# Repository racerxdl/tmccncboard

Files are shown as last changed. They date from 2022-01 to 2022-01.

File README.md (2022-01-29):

# tmccncboard

TMC2209 GRBL-ESP32 CNC Board

Made with Kicad 6.0

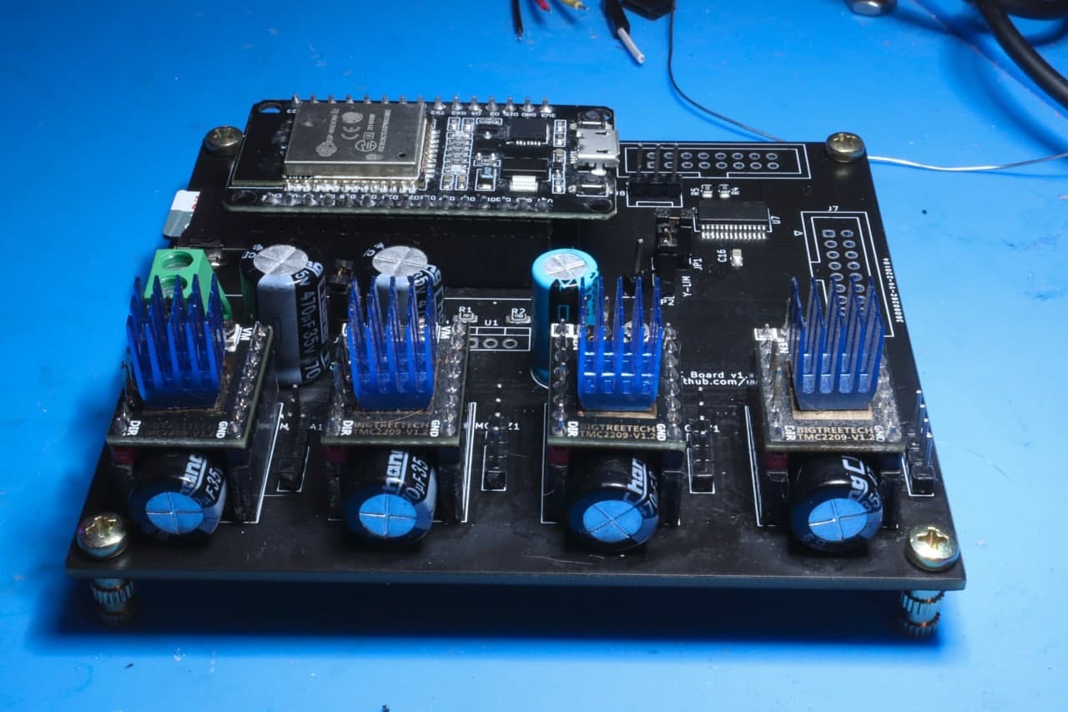
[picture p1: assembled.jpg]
Assembled Board


# FluidNC Configuration

This is the current profile I'm using for [FluidNC](https://github.com/bdring/FluidNC). Its currently WIP and should be used with care.

```yaml
board: Teske's Lab TMC CNC
name: TMCCNC
stepping:
  engine: RMT
  idle_ms: 255
  pulse_us: 2
  dir_delay_us: 1
  disable_delay_us: 0

axes:
  shared_stepper_disable_pin: gpio.27
  x:
    steps_per_mm: 1600.000
    max_rate_mm_per_min: 5000.000
    acceleration_mm_per_sec2: 100.000
    max_travel_mm: 250.000
    soft_limits: false
    homing:
      cycle: 2
      positive_direction: false
      mpos_mm: 150.000
      feed_mm_per_min: 100.000
      seek_mm_per_min: 200.000
      settle_ms: 500
      seek_scaler: 1.100
      feed_scaler: 1.100

    motor0:
      limit_neg_pin: NO_PIN
      limit_pos_pin: NO_PIN
      limit_all_pin: gpio.36
      hard_limits: false
      pulloff_mm:1.000

      tmc_2209:
        uart:
          txd_pin: gpio.17
          rxd_pin: gpio.16
        run_mode: StealthChop
        homing_mode: StallGuard
        step_pin: gpio.2
        direction_pin: gpio.4
        addr: 0
        r_sense_ohms: 0.110
        run_amps: 1.000
        hold_amps: 0.500
        microsteps: 16
  y:
    steps_per_mm: 400.000
    max_rate_mm_per_min: 5000.000
    acceleration_mm_per_sec2: 100.000
    max_travel_mm: 490.000
    soft_limits: false
    homing:
      cycle: 2
      positive_direction: true
      mpos_mm: 150.000
      feed_mm_per_min: 100.000
      seek_mm_per_min: 200.000
      settle_ms: 500
      seek_scaler: 1.100
      feed_scaler: 1.100

    motor0:
      limit_neg_pin: NO_PIN
      limit_pos_pin: NO_PIN
      limit_all_pin: gpio.39
      hard_limits: false
      pulloff_mm:1.000

      tmc_2209:
        run_mode: StealthChop
        homing_mode: StallGuard
        step_pin: gpio.12
        direction_pin: gpio.14
        addr: 1
        r_sense_ohms: 0.110
        run_amps: 1.000
        hold_amps: 0.500
        microsteps: 16

    motor1:
      limit_neg_pin: NO_PIN
      limit_pos_pin: NO_PIN
      limit_all_pin: gpio.34
      hard_limits: false
      pulloff_mm: 1.000
      tmc_2209:
        run_mode: StealthChop
        homing_mode: StallGuard
        step_pin: gpio.33
        direction_pin: gpio.32
        addr: 3
        r_sense_ohms: 0.110
        run_amps: 1.000
        hold_amps: 0.500
        microsteps: 16

  z:
    steps_per_mm: 400.000
    max_rate_mm_per_min: 5000.000
    acceleration_mm_per_sec2: 100.000
    max_travel_mm: 100.000
    soft_limits: false
    homing:
      cycle: 1
      positive_direction: true
      mpos_mm: 150.000
      feed_mm_per_min: 100.000
      seek_mm_per_min: 800.000
      settle_ms: 500
      seek_scaler: 1.100
      feed_scaler: 1.100

    motor0:
      limit_neg_pin: NO_PIN
      limit_pos_pin: NO_PIN
      limit_all_pin: gpio.35
      hard_limits: false
      pulloff_mm:1.000

      tmc_2209:
        run_mode: StealthChop
        homing_mode: StallGuard
        step_pin: gpio.26
        direction_pin: gpio.25
        addr: 2
        r_sense_ohms: 0.110
        run_amps: 1.000
        hold_amps: 0.500
        microsteps: 16

spi:
  miso_pin: gpio.19
  mosi_pin: gpio.23
  sck_pin: gpio.18

sdcard:
  cs_pin: gpio.5
  card_detect_pin: NO_PIN

probe:
  pin: NO_PIN
  check_mode_start: true

start:
  must_home: false

PWM:
  pwm_hz: 5000
  output_pin: gpio.13
  enable_pin: NO_PIN
  direction_pin: NO_PIN
  disable_with_s0: false
  s0_with_disable: true
  spinup_ms: 1000
  spindown_ms: 1000
  tool_num: 0
  speed_map: 0=0.000% 1000=100.000%

```

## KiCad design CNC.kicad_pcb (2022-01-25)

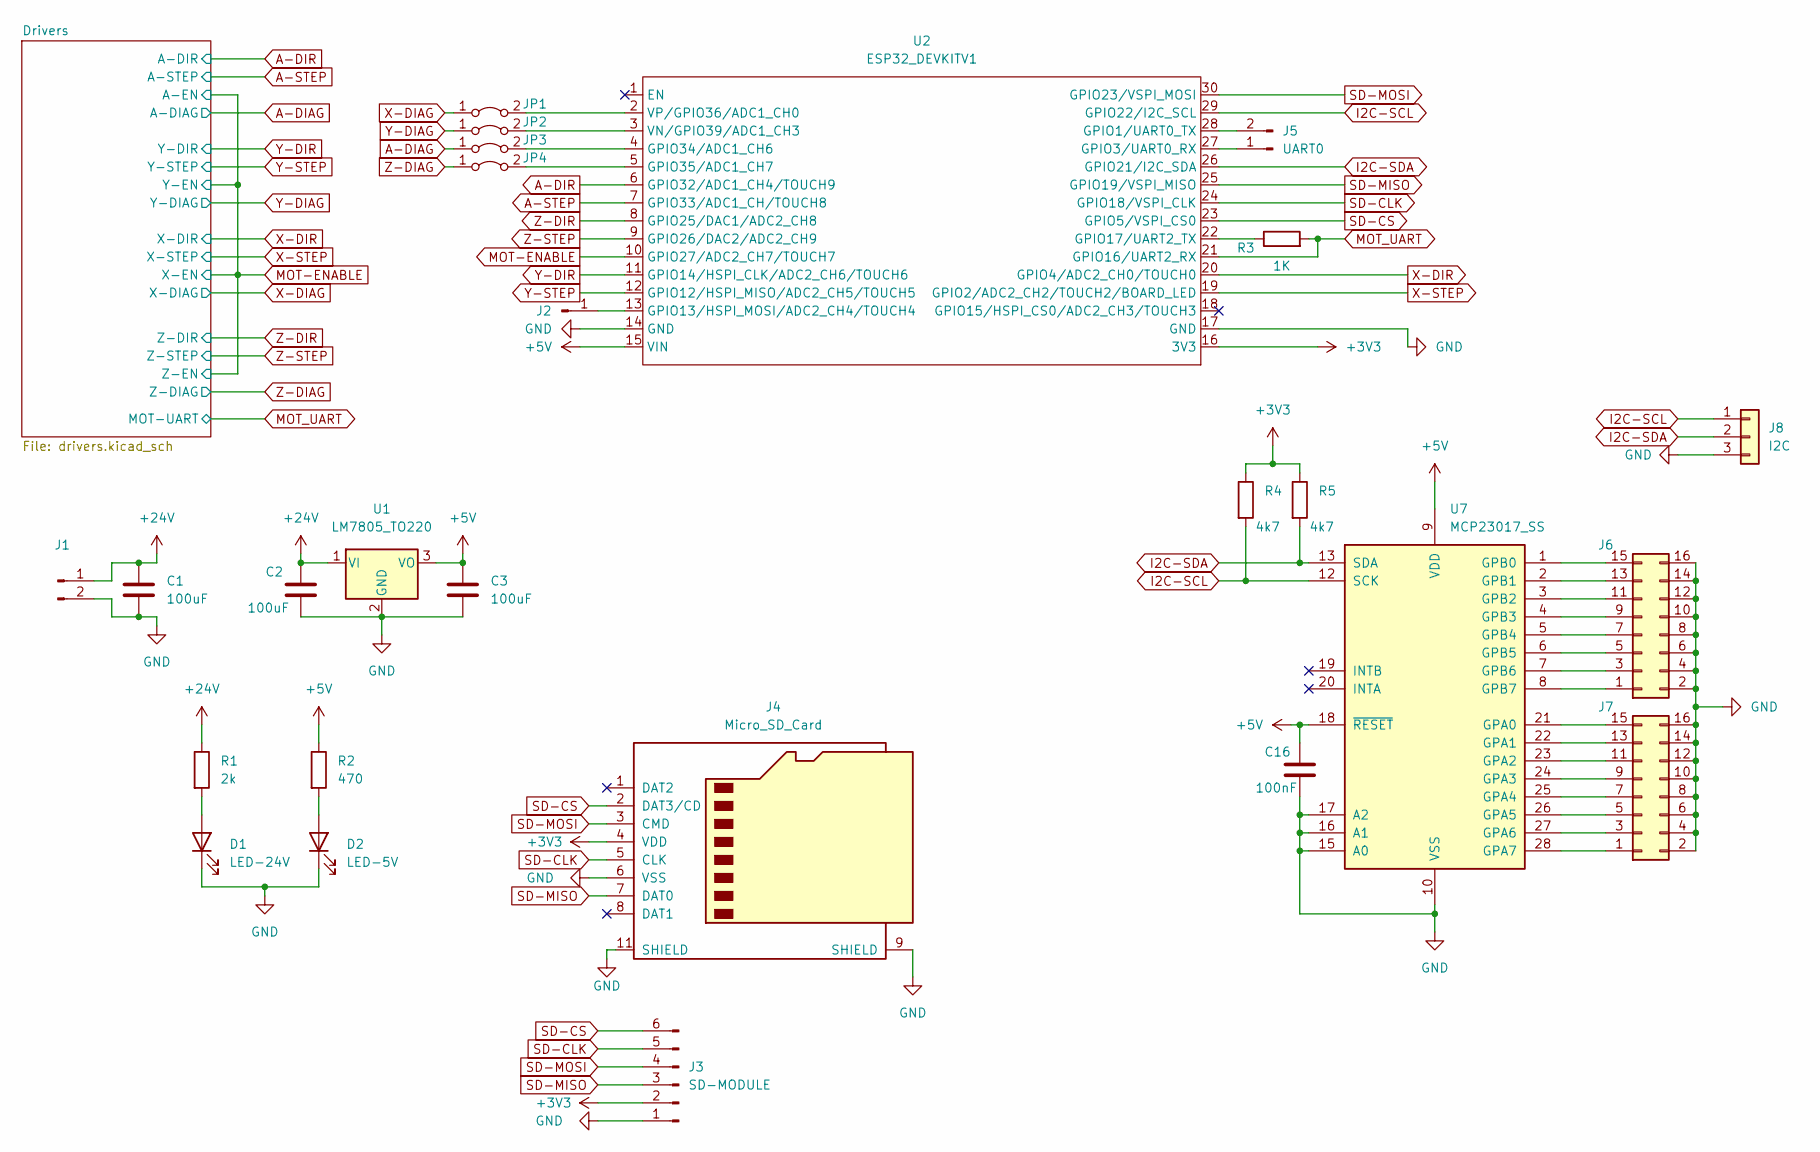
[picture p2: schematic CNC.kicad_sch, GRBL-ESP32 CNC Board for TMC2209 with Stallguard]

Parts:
C1, C2, C3: 100uF; CP_Radial_D8.0mm_P3.50mm
C16: 100nF; C_0805_2012Metric_Pad1.18x1.45mm_HandSolder
D1: LED-24V; LED_D5.0mm
D2: LED-5V; LED_D5.0mm
J1: Conn_01x02_Male; Altech_AK300_1x02_P5.00mm_45-Degree
J2: Conn_01x01_Male; PinHeader_1x01_P2.54mm_Vertical
J3: SD-MODULE; PinHeader_1x06_P2.54mm_Horizontal
J4: Micro_SD_Card; microSD_HC_Hirose_DM3AT-SF-PEJM5
J5: UART0; PinHeader_1x02_P2.54mm_Vertical
J6, J7: Conn_02x08_Odd_Even; IDC-Header_2x08_P2.54mm_Vertical
J8: I2C; FanPinHeader_1x03_P2.54mm_Vertical
JP1, JP2, JP3, JP4: Jumper_2_Bridged; PinHeader_1x02_P2.54mm_Vertical
R1: 2k; R_0805_2012Metric_Pad1.20x1.40mm_HandSolder
R2: 470; R_0805_2012Metric_Pad1.20x1.40mm_HandSolder
R3: 1K; R_0805_2012Metric_Pad1.20x1.40mm_HandSolder
R4, R5: 4k7; R_0805_2012Metric_Pad1.20x1.40mm_HandSolder
U1: LM7805_TO220; TO-220-3_Vertical
U2: ESP32_DEVKITV1; ESP32 DEVKITV1
U7: MCP23017_SS; SSOP-28_5.3x10.2mm_P0.65mm

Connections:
+3V3: J3.2, J4.4 (VDD), R4.1, R5.1, U2.16 (3V3); also elsewhere on the board
+5V: C3.1, C16.1, R2.1, U1.3 (VO), U2.15 (VIN), U7.9 (VDD), U7.18 (~RESET)
+24V: C1.1, C2.1, J1.1, R1.1, U1.1 (VI); also elsewhere on the board
A-DIAG: JP3.1 (A); also elsewhere on the board
A-DIR: U2.6 (GPIO32/ADC1_CH4/TOUCH9); also elsewhere on the board
A-STEP: U2.7 (GPIO33/ADC1_CH/TOUCH8); also elsewhere on the board
GND: C1.2, C2.2, C3.2, C16.2, D1.1 (K), D2.1 (K), J1.2, J3.1, J4.6 (VSS), J4.9 (SHIELD), J4.11 (SHIELD), J6.2, J6.4, J6.6, J6.8, J6.10, J6.12, J6.14, J6.16, J7.2, J7.4, J7.6, J7.8, J7.10, J7.12, J7.14, J7.16, J8.3, U1.2 (GND), U2.14 (GND), U2.17 (GND), U7.10 (VSS), U7.15 (A0), U7.16 (A1), U7.17 (A2); also elsewhere on the board
I2C-SCL: J8.1, R4.2, U2.29 (GPIO22/I2C_SCL), U7.12 (SCK)
I2C-SDA: J8.2, R5.2, U2.26 (GPIO21/I2C_SDA), U7.13 (SDA)
MOT-ENABLE: U2.10 (GPIO27/ADC2_CH7/TOUCH7); also elsewhere on the board
MOT_UART: R3.2, U2.21 (GPIO16/UART2_RX); also elsewhere on the board
unnamed: D1.2 (A), R1.2
unnamed: D2.2 (A), R2.2
unnamed: J2.1, U2.13 (GPIO13/HSPI_MOSI/ADC2_CH4/TOUCH4)
unnamed: J5.1, U2.27 (GPIO3/UART0_RX)
unnamed: J5.2, U2.28 (GPIO1/UART0_TX)
unnamed: J6.1, U7.8 (GPB7)
unnamed: J6.3, U7.7 (GPB6)
unnamed: J6.5, U7.6 (GPB5)
unnamed: J6.7, U7.5 (GPB4)
unnamed: J6.9, U7.4 (GPB3)
unnamed: J6.11, U7.3 (GPB2)
unnamed: J6.13, U7.2 (GPB1)
unnamed: J6.15, U7.1 (GPB0)
unnamed: J7.1, U7.28 (GPA7)
unnamed: J7.3, U7.27 (GPA6)
unnamed: J7.5, U7.26 (GPA5)
unnamed: J7.7, U7.25 (GPA4)
unnamed: J7.9, U7.24 (GPA3)
unnamed: J7.11, U7.23 (GPA2)
unnamed: J7.13, U7.22 (GPA1)
unnamed: J7.15, U7.21 (GPA0)
unnamed: JP1.2 (B), U2.2 (VP/GPIO36/ADC1_CH0)
unnamed: JP2.2 (B), U2.3 (VN/GPIO39/ADC1_CH3)
unnamed: JP3.2 (B), U2.4 (GPIO34/ADC1_CH6)
unnamed: JP4.2 (B), U2.5 (GPIO35/ADC1_CH7)
unnamed: R3.1, U2.22 (GPIO17/UART2_TX)
SD-CLK: J3.5, J4.5 (CLK), U2.24 (GPIO18/VSPI_CLK)
SD-CS: J3.6, J4.2 (DAT3/CD), U2.23 (GPIO5/VSPI_CS0)
SD-MISO: J3.3, J4.7 (DAT0), U2.25 (GPIO19/VSPI_MISO)
SD-MOSI: J3.4, J4.3 (CMD), U2.30 (GPIO23/VSPI_MOSI)
X-DIAG: JP1.1 (A); also elsewhere on the board
X-DIR: U2.20 (GPIO4/ADC2_CH0/TOUCH0); also elsewhere on the board
X-STEP: U2.19 (GPIO2/ADC2_CH2/TOUCH2/BOARD_LED); also elsewhere on the board
Y-DIAG: JP2.1 (A); also elsewhere on the board
Y-DIR: U2.11 (GPIO14/HSPI_CLK/ADC2_CH6/TOUCH6); also elsewhere on the board
Y-STEP: U2.12 (GPIO12/HSPI_MISO/ADC2_CH5/TOUCH5); also elsewhere on the board
Z-DIAG: JP4.1 (A); also elsewhere on the board
Z-DIR: U2.8 (GPIO25/DAC1/ADC2_CH8); also elsewhere on the board
Z-STEP: U2.9 (GPIO26/DAC2/ADC2_CH9); also elsewhere on the board

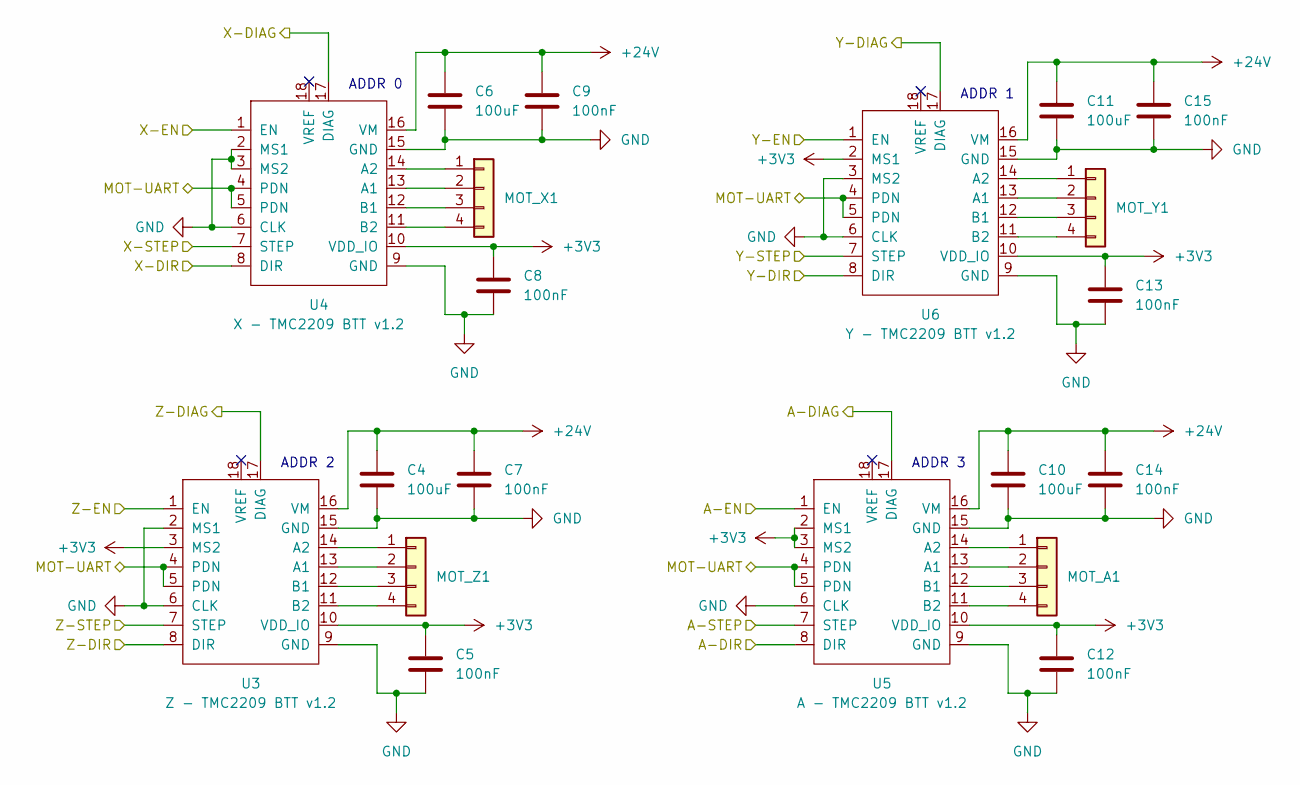
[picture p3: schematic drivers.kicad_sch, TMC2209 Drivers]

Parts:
C4, C6, C10, C11: 100uF; CP_Radial_D8.0mm_P3.50mm
C5, C7, C8, C9, C12, C13, C14, C15: 100nF; C_0805_2012Metric_Pad1.18x1.45mm_HandSolder
MOT_A1: Conn_01x04; PinHeader_1x04_P2.54mm_Vertical
MOT_X1: Conn_01x04; PinHeader_1x04_P2.54mm_Vertical
MOT_Y1: Conn_01x04; PinHeader_1x04_P2.54mm_Vertical
MOT_Z1: Conn_01x04; PinHeader_1x04_P2.54mm_Vertical
U3: Z - TMC2209 BTT v1.2; BTT-TMC2209
U4: X - TMC2209 BTT v1.2; BTT-TMC2209
U5: A - TMC2209 BTT v1.2; BTT-TMC2209
U6: Y - TMC2209 BTT v1.2; BTT-TMC2209

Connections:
+3V3: C5.1, C8.1, C12.1, C13.1, U3.3 (MS2), U3.10 (VDD_IO), U4.10 (VDD_IO), U5.2 (MS1), U5.3 (MS2), U5.10 (VDD_IO), U6.2 (MS1), U6.10 (VDD_IO); also elsewhere on the board
+24V: C4.1, C6.1, C7.1, C9.1, C10.1, C11.1, C14.1, C15.1, U3.16 (VM), U4.16 (VM), U5.16 (VM), U6.16 (VM); also elsewhere on the board
A-DIAG: U5.17 (DIAG); also elsewhere on the board
A-DIR: U5.8 (DIR); also elsewhere on the board
A-STEP: U5.7 (STEP); also elsewhere on the board
GND: C4.2, C5.2, C6.2, C7.2, C8.2, C9.2, C10.2, C11.2, C12.2, C13.2, C14.2, C15.2, U3.2 (MS1), U3.6 (CLK), U3.9 (GND), U3.15 (GND), U4.2 (MS1), U4.3 (MS2), U4.6 (CLK), U4.9 (GND), U4.15 (GND), U5.6 (CLK), U5.9 (GND), U5.15 (GND), U6.3 (MS2), U6.6 (CLK), U6.9 (GND), U6.15 (GND); also elsewhere on the board
MOT-ENABLE: U3.1 (EN), U4.1 (EN), U5.1 (EN), U6.1 (EN); also elsewhere on the board
MOT_UART: U3.4 (PDN), U3.5 (PDN), U4.4 (PDN), U4.5 (PDN), U5.4 (PDN), U5.5 (PDN), U6.4 (PDN), U6.5 (PDN); also elsewhere on the board
unnamed: MOT_A1.1, U5.14 (A2)
unnamed: MOT_A1.2, U5.13 (A1)
unnamed: MOT_A1.3, U5.12 (B1)
unnamed: MOT_A1.4, U5.11 (B2)
unnamed: MOT_X1.1, U4.14 (A2)
unnamed: MOT_X1.2, U4.13 (A1)
unnamed: MOT_X1.3, U4.12 (B1)
unnamed: MOT_X1.4, U4.11 (B2)
unnamed: MOT_Y1.1, U6.14 (A2)
unnamed: MOT_Y1.2, U6.13 (A1)
unnamed: MOT_Y1.3, U6.12 (B1)
unnamed: MOT_Y1.4, U6.11 (B2)
unnamed: MOT_Z1.1, U3.14 (A2)
unnamed: MOT_Z1.2, U3.13 (A1)
unnamed: MOT_Z1.3, U3.12 (B1)
unnamed: MOT_Z1.4, U3.11 (B2)
X-DIAG: U4.17 (DIAG); also elsewhere on the board
X-DIR: U4.8 (DIR); also elsewhere on the board
X-STEP: U4.7 (STEP); also elsewhere on the board
Y-DIAG: U6.17 (DIAG); also elsewhere on the board
Y-DIR: U6.8 (DIR); also elsewhere on the board
Y-STEP: U6.7 (STEP); also elsewhere on the board
Z-DIAG: U3.17 (DIAG); also elsewhere on the board
Z-DIR: U3.8 (DIR); also elsewhere on the board
Z-STEP: U3.7 (STEP); also elsewhere on the board

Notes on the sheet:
ADDR 2
ADDR 1
ADDR 3
ADDR 0

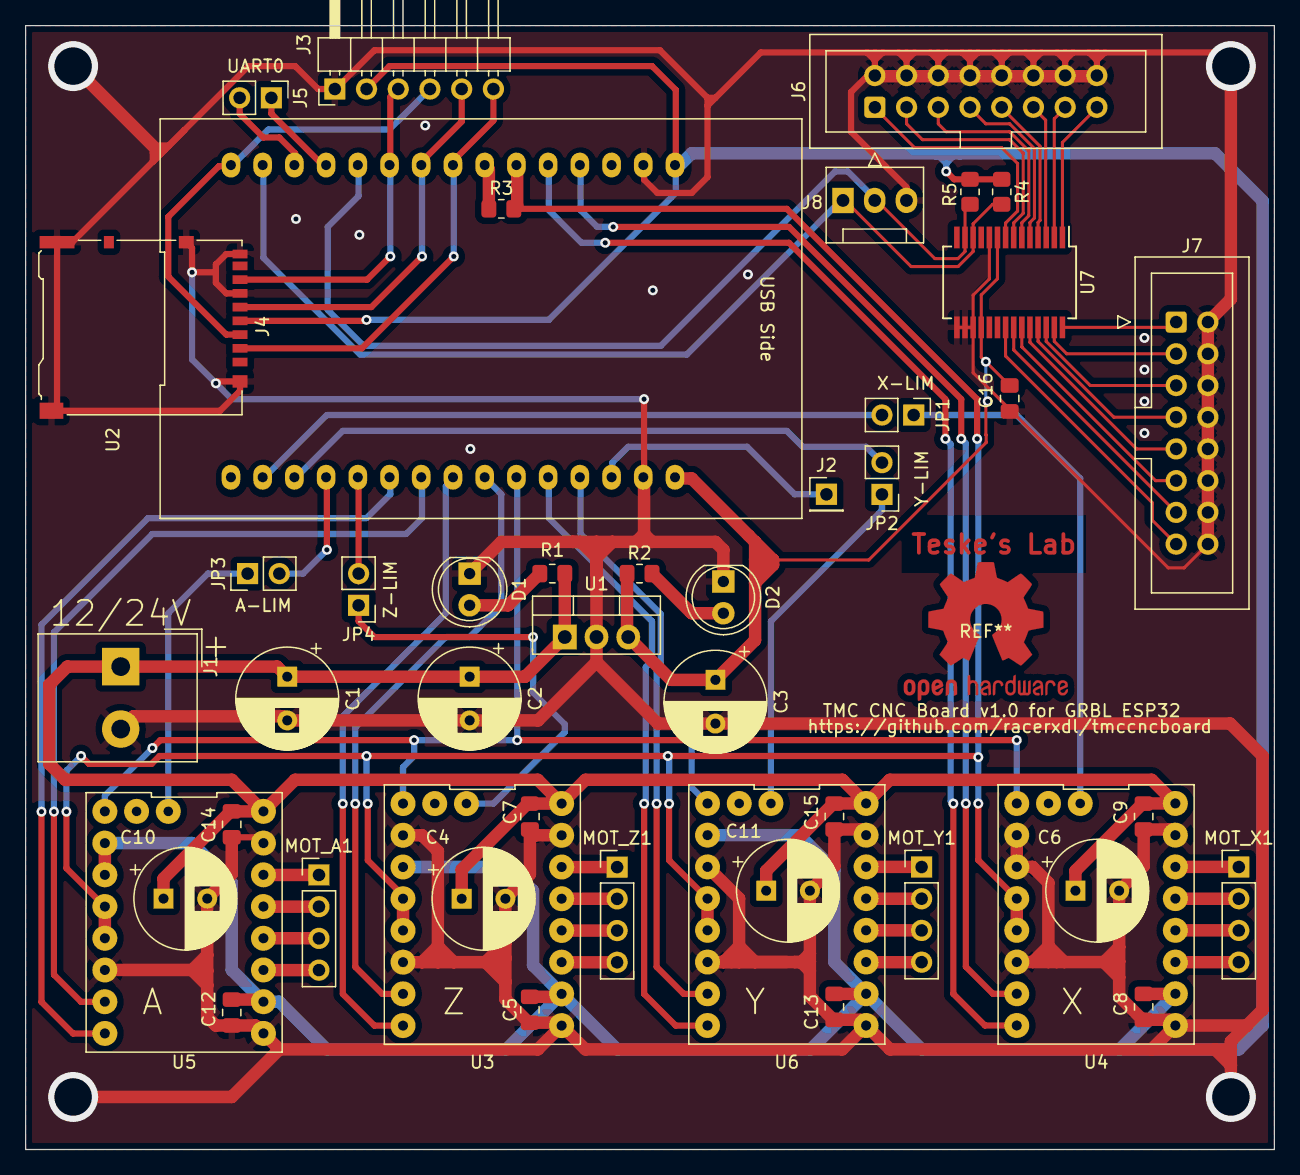
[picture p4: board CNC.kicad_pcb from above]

Board: 2 copper layers, 100.0 x 90.0 mm, 46 parts (0 on the bottom side), 66 nets.

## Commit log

2022-01-03 Add preliminary gerber files
    [CNC-Cobre traseira.gbr, CNC-Cortes contorno.gbr, CNC-Máscara frontal.gbr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]
2022-01-04 Added I/O Expander and fixed DRC
    [CNC-Cobre frontal.gbr, CNC-Cobre traseira.gbr, CNC-Cortes contorno.gbr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]
2022-01-25 Fix ESP32-USB direction on PCB
    [CNC.kicad_pcb]
